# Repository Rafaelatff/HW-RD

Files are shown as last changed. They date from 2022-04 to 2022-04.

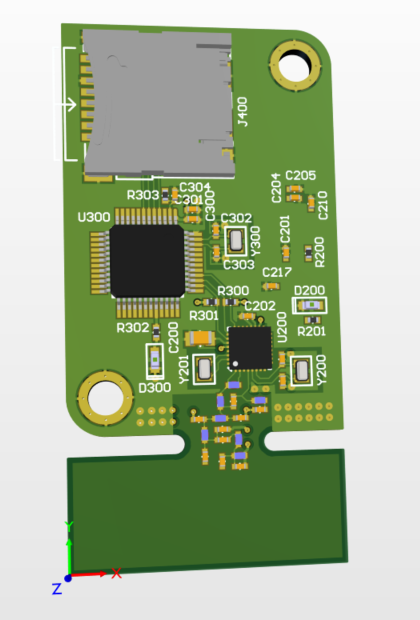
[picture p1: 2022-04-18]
3D files/Challenge-NOT-FINISHED.png

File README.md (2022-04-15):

# HW-RD
TRACTIAN challenge - Hardware R&amp;D

*Goal: Develop a full wireless communication system. It needs to send a 500 kB file from a 100 m open-air gap, using at least one battery powered device.*

## Step 1: Scketch it up! 

**1.1 - Let's find the main wireless component**

The preference for manufacturer goes to Texas Instruments due its good variety of components, good documentation, tools for simulation and development. 

According to: https://training.ti.com/range-test-cc1120-sub-1-ghz-performance-line, 100 m air-gap is reachable with a Sub-1GHz system.

Texas instruments shows 36 parts classified as Sub-1GHz products. All 36 were checked, but only active part numbers and with at least one place with available stock entered the comparing table below. Preference for available SPI to add external memory. There were no operating temperature requirements for the wireless communication system, nor minimum of peripheral required.  So none of those were considered componente elimination factors. It is a battery powered device, so, it must be low power.
The table below compares TI inventory and also Mouser and Digikey (two biggest global electronic components purveyor).

| Part Number | TI Inventory | Price | Mouser | Price | Digikey | Price |
|---|---|---|---|---|---|---|
| CC1311P3 | 2418 | $3.125 | Non-Stocked | $4.8 (x2500) | 0 | $8.92 |
| CC1312R7 | 2200 | $3.795 | Non-Stocked | $5.83 (x2500) | - | - |
| CC1352P | 0 | $3.917 | CC1352P1F3RGZT -107 CC1352P1F3RGZR – 5061 (On order) | $11.86 $9.89 | 0 | $9.4 |
| CC1312R | 0 | $3.341 | CC1312R1F3RGZR (7806 Expected 10/3/2022) | $8.43 | 0 | $8.02 |
| CC430F5143 | 376 | $2.34 | Non-Stocked | $5.05 (x250) | CC430F5143IRGZT - 250 | $6.74 |
| **CC1350** | **5167** | **$3.446** | **CC1350F128RSMR – 5148 CC1350F128RSMT - 257** | **$8.96 $10.7** | **CC1350F128RSMR – 841 CC1350F128RHBR - 644** | **$9.37 $8.27** |
| **CC1310** | **19084** | **$2.052** | **CC1310F32RSMR – 11472 CC1310F32RGZR - 1318** | **$5.76 $6.05** | **CC1310F128RGZR – 2212 CC1310F32RGZT - 214** | **$6.89 $6.15** |
| CC1200 | 7990 | $1.928 | 0 | $5.42 | 0 | $6.48 |
| CC1100E | 0 | $1.139 | CC1100ERGPT - 57 | $3.84 | CC1100ERGPT - 149 | $3.83 |

Note : research done in April, 11th. 
https://www.ti.com/wireless-connectivity/products.html 
https://br.mouser.com/
https://www.digikey.com

Now, let's compare Technologies. Note: values from TI site - production details (datasheet may show accurate data and were not considered, since it consumes a lot of time).

| Part Number | Available devkit? | Microcontroller | Peripherals | Memory | Power (active mode/standby mode/transmission mode*) |
|---|---|---|---|---|---|
| CC1311P3 | Not found | 48-MHz Arm Cortex-M4 processor | 1 SPI, 1 UART, 12-bit ADC 8-channel, 2 comparators, 4 timers, I2C, I2S, 26 GPIO | 32 KB RAM + 352 KB flash | 2.63 mA/ 0.7 uA / 65 mA |
| CC1312R7 | LP-CC1312R7 (10 - $69.94) | 48-MHz Arm® Cortex®-M4F processor | 12-bit ADC 8-channel, 2 SPI, 2 UART, 2 comparators, 4 timers, 8-bit DAC, I2C, I2S, Sensor controller, 30 GPIO | 256 KB ROM+ 704 KB flash | 2.63 mA/ 0.8 uA / 24.9 mA |
| CC1352P | LAUNCHXL-CC1352P1 (183 - $66.49)  | 48-MHz Arm Cortex-M4F processor | 2 SPI, 2 UART, 2 comparators, 4 timers, 8-bit DAC, I2S, Sensor controller, 26 GPIO | 256 KB ROM + 352 KB flash | 5.8 mA/ 0.85 uA / 24.9 mA |
| CC1312R | LAUNCHXL-CC1312R1 (85 - $53.19) | 48-MHz Arm Cortex-M4F processor | 2 SPI, 2 UART, 2 comparators, 4 timers, 12-bit ADC, I2S, Sensor controller, 30 GPIO | 80KB SRAM + 256 KB ROM + 352 KB flash | 5.8 mA/ 0.85 uA / 24.9 mA |
| CC430F5143 | Not found | True System-on-Chip (SoC) for Low-Power Wireless Communication Applications / 16-Bit RISC Architecture | I2C, UART,  2x SPI, 2 timers, 10-bit ADC | 4 KB RAM +  32 KB flash | 160 uA / 2 uA/ 15 mA |
| CC1350 | CC1350STKUS (82 - $78.47) LAUNCHXL-CC1350US (22 - $38.57) | 48-MHz Arm® Cortex®-M3 Processor | 1 UART, 12-bit ADC 8-channel, 2 SPI, 2 comparators, 4 timers, I2C, I2S, Sensor controller, GPIO according to package (10, 15 or 30) | 28KB SRAM + 128 KB flash | 5.4 mA/ 0.7 uA/ 13.4 mA |
| CC1310 | LAUNCHXL-CC1310 (122 - $38.57) | 48-MHz Arm® Cortex®-M3 | 1 UART, 12-bit ADC 8-channel, 2 SPI, 2 comparators, 4 timers, I2C, I2S, Sensor controller, GPIO according to package (10, 15 or 30) | 28 KB SRAM + 128 KB flash | 5.4 mA/ 0.7 uA/ 13.4 mA |

Note : To have an available devkit helps development tasks (once production firmware may start together with hardware development and even help to find issues).  Let's not forget of the  time to market..

Links: 
https://training.ti.com/ti-simplelink-sub-1-ghz-wireless-solutions-iot-technical-introduction-level-1

https://www.ti.com/design-resources/embedded-development/wireless-connectivity.html

https://www.ti.com/lit/sg/swat016b/swat016b.pdf

CC1310 User guide: https://www.ti.com/lit/ug/swcu117i/swcu117i.pdf

CC1310 Datasheet: https://www.ti.com/lit/ds/symlink/cc1310.pdf

Xtal selection guideline: https://www.ti.com/lit/an/swra495i/swra495i.pdf (not really followed due to small amount of time available to the challenge)

**Pin mapping - RSM Package (VQFN-32)**

| Pin name | Pin number | Type | Description | 
|---|---|---|---|
| DCDC_SW | 18 | Power | Output from internal DC/DC |
| DCOUPL | 12 | Power | 1.27-V regulated digital-supply decoupling capacitor |
| DIO_0 | 8 | Digital I/O | GPIO, Sensor Controller, high-drive capability |
| DIO_1 | 9 | Digital I/O | GPIO, Sensor Controller, high-drive capability |
| DIO_2 | 10 | Digital I/O | GPIO, Sensor Controller, high-drive capability |
| DIO_3 | 15 | Digital I/O | GPIO, high-drive capability, JTAG_TDO |
| DIO_4 | 16 | Digital I/O | GPIO, high-drive capability, JTAG_TDI |
| DIO_5 | 22 | Digital or analog I/O | GPIO, Sensor Controller, analog |
| DIO_6 | 23 | Digital or analog I/O | GPIO, Sensor Controller, analog |
| DIO_7 | 24 | Digital or analog I/O | GPIO, Sensor Controller, analog |
| DIO_8 | 25 | Digital or analog I/O | GPIO, Sensor Controller, analog |
| DIO_9 | 26 | Digital or analog I/O | GPIO, Sensor Controller, analog |
| EGP | - | Power | Ground; exposed ground pad |
| JTAG_TMSC | 13 | Digital I/O | JTAG_TMSC |
| JTAG_TCKC | 14 | Digital I/O | JTAG_TCKC |
| RESET_N  | 21 | Digital input | Reset, active low. No internal pullup |
| RF_N | 2 | RF I/O  | Negative RF input signal to LNA during RX Negative RF output signal from PA during TX |
| RF_P | 1 | RF I/O | Positive RF input signal to LNA during RX Positive RF output signal from PA during TX |
| RX_TX | 4 | RF I/O  | Optional bias pin for the RF LNA |
| VDDS | 27 | Power | 1.8-V to 3.8-V main chip supply |
| VDDS2 | 11 | Power | 1.8-V to 3.8-V GPIO supply |
| VDDS_DCDC | 19 | Power | 1.8-V to 3.8-V DC/DC supply |
| VDDR | 28 | Power | 1.7-V to 1.95-V supply, connect to output of internal DC/DC |
| VDDR_RF | 31 | Power | 1.7-V to 1.95-V supply, connect to output of internal DC/DC |
| VSS | 3, 7, 17, 20, 29  | Power | Ground |
| X32K_Q1 | 5 | Analog I/O | 32-kHz crystal oscillator pin 1 |
| X32K_Q2 | 6 | Analog I/O | 32-kHz crystal oscillator pin 2 |
| X24M_N | 30 | Analog I/O | 24-MHz crystal oscillator pin 1 |
| X24M_P | 31 | Analog I/O | 24-MHz crystal oscillator pin 2 |

**1.2 - Let's find the hw peripherals**

**1.2.1 - Power supply**

Function and characteristics: filter and regulate battery voltage; low LDO; low quiescent current; 

**1.2.2 - Secondary low power microcontroller**

Function and characteristics: control and manage secondary tasks; comunicate with wireless microcontroller; low power;

PN: MSP430FR2476 Mnf: Texas Instruments Datasheet: www.ti.com/lit/ds/symlink/msp430fr2476.pdf

Used pins:
| Pin number | Port.Pin | Type/Peripheral | Description | 
|---|---|---|---|
| 1 | DVCC | Power | VDD |
| 2 | SBW | JTAG/SBW | JTAG/SBW |
| 3 | SBW | JTAG/SBW | JTAG/SBW |
| 4 | P1.4 | UCA0SIMO | eUSCI_A0 SPI slave in/master out |
| 5 | P1.5 | UCA0SOMI | eUSCI_A0 SPI slave out/master in |
| 6 | P1.6 | UCA0CLK | eUSCI_A0 SPI clock input/output |
| 7 | P1.7 | UCA0STE |  eUSCI_A0 SPI slave transmit enable |
| 8 | P4.3 | GPIO | SPI_INT |
| 37 | P3.5 | GPIO | I2C_INT |
| 38 | P3.2 | UCB1SDA | eUSCI_B1 I2C data |
| 39 | P3.6 | UCB1SCL | eUSCI_B1 I2C clock |
| 46 | XOUT | Xtal | Crystal out |
| 47 | XIN | Xtal | Crystal in |
| 48 | DVSS | Power | GND |

**1.2.3 - External memory or microSD card**

Function and characteristics: accomodate data; save logs; SPI communication;

Guidelines: 
https://www.kingston.com/datasheets/SDCIT-specsheet-64gb_en.pdf
https://www.st.com/resource/en/application_note/an5595-spc58xexspc58xgx-multimedia-card-via-spi-interface-stmicroelectronics.pdf

microSD card connector PN: DM3C-SF / Manufacturer: Hirose Electric Co Ltd 

**1.2.4 - Accelerometer**

Function and characteristics: main parameter to be monitored;

**1.2.5 - Battery**

Function and characteristics: 3.6 V; Lithium batteries (ultra-low power);

## Step 2: It’s layout time

For Altium project -> HW-RD/tree/main/Altium%20Project

For 3D project -> HW-RD/tree/main/3D%20files

Antenna guidelines: https://www.ti.com/lit/an/swra726/swra726.pdf

Layout must have the rules according to the capability of the third party company that will manufacturer the PCB (example: https://www.griffuspcb.com.br/files/anexo1-34-parametros-de-processo-e-produto-rev-05.pdf). Impedance values for PCB tracks must follow recommendation of third party company that will manufacturer the PCB together with Saturn PCB toolkit. Since time is short, just Saturn PCB toolkit will be used.

## Step 3: Write some code!

For CC1310 code -> HW-RD/tree/main/CC1310

For MSP430 code -> HW-RD/tree/main/MSP430

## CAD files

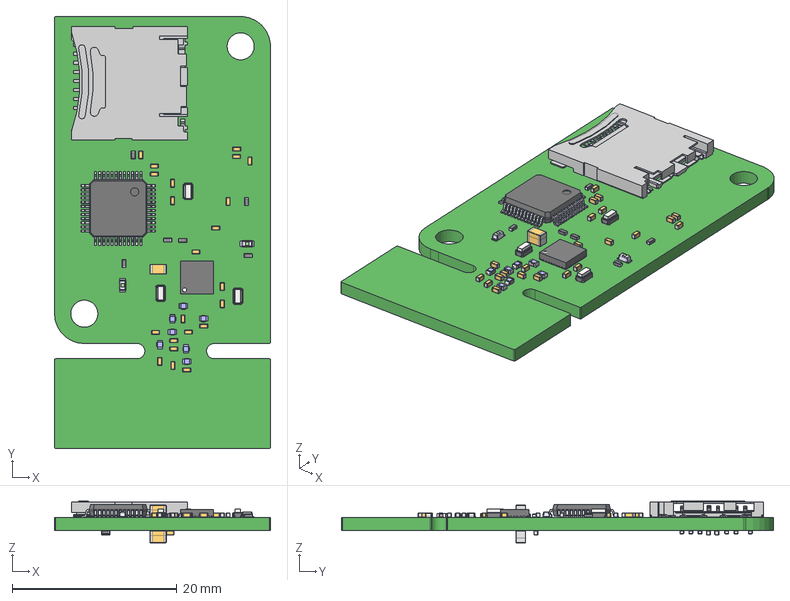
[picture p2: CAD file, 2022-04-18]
3D files/TRACTIAN-HW-Challenge.step
26.3 x 52.5 x 5.06 mm
Board
R0402 x 12
LED_SMD_0603 x 2
Extruded x 5
CAPC1005X56N_EIA_0402 x 25
Coilcraft-0402ME x 7
User_Library-ABS06_ABS06_Body_2 x 3
User_Library-ABS06_ABS06_Body2_2 x 3
User_Library-ABS06_ABS06_Beschriftung_2 x 3
User_Library-ABS06_ABS06_Pads_2 x 3
CAPC2012X95N_EIA_0805 x 4
DM3CS-SF
LQFP48_Koerper_2
LQFP_PIN_2 x 48
pins
pins_small x 32
pin_label x 8

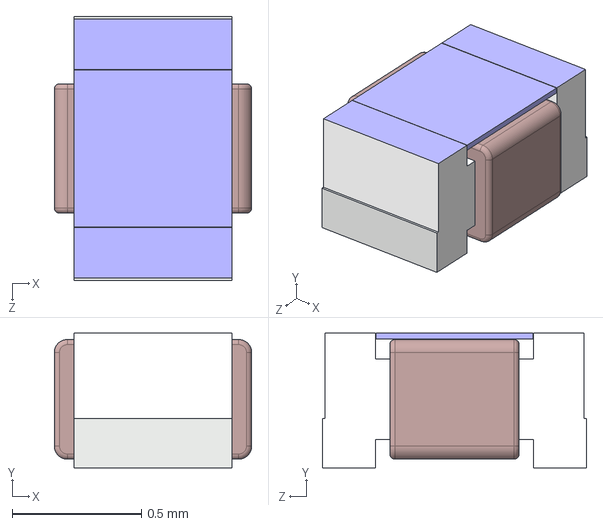
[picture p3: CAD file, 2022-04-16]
Altium Project/3D parts/Coilcraft-0402ME.STEP
0.762 x 0.521 x 1.02 mm

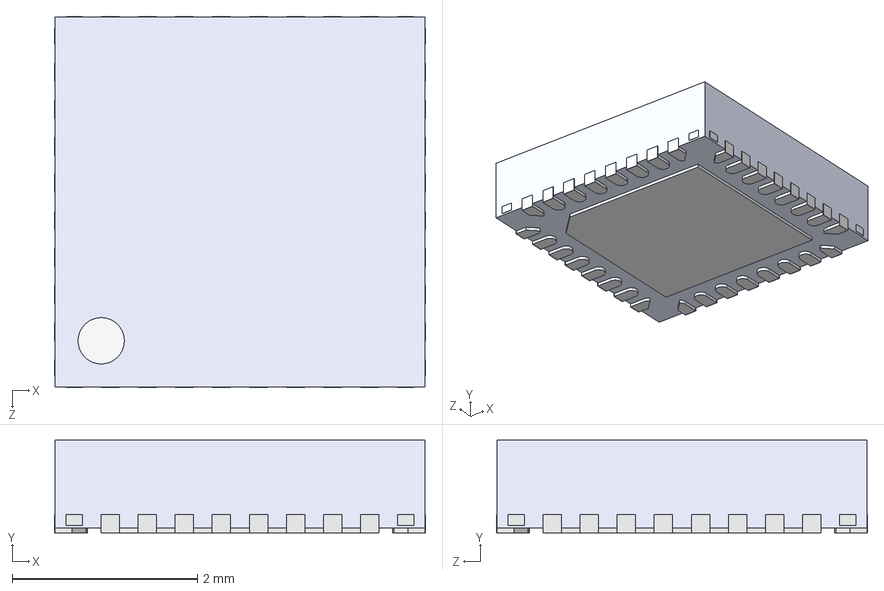
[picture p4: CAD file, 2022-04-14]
Altium Project/3D parts/User Library-QFN32-0_4.STEP
4.01 x 1.00 x 4.01 mm
pins
pins_small x 32
pin_label x 8

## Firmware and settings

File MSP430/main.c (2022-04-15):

//CCS version 10.2.0.00009
#include <msp430.h>
#include <string.h> //to use strlen() function
#include <assert.h> // to use asset function
#include <stdio.h>

char message = 0;
char Data_In = 0;


int x = 19;
int y=0;
//size 20, goes from Data_In_Array[0] until Data_In_Array[19], being [0] reg addred + [0x00 to 0x12] data
char Data_In_Array[20];

int ACLK_clock;

void I2C_B1_slave_config(void);
void SPI_A0_config(void);
int BCDtoDecimal(int data);
int DecimalToBCD(int data); //not needed!
void delay_ms(int time);
void start_clock_sys(void);

int main(void)
{
     WDTCTL = WDTPW | WDTHOLD;   // stop watchdog timer

    // Set LED1 for test routines
    // Set P1.0 as output direction [J7 needs to be connected]
    // LED White: Port P1 / Pin 0
    P1SEL0 &= ~BIT0;
    P1SEL1 &= ~BIT0;
    P1DIR |= BIT0; // Set LED1 as Output
    P1OUT &= ~BIT0; // turn off LED1

    PM5CTL0 &= ~LOCKLPM5;       //to apply the GPIO configurations disable the LOCKLPM5 bit in PM5CTL0
    //unlock the GPIO high-impedance mode by resetting the LOCKLPM5 bit

    I2C_B1_slave_config(); // Config MSP as slave

    P1OUT |= BIT0; // LED1

    while (1){

        __delay_cycles(78000);
        P1OUT ^= BIT0; // LED0
    }
}
//-------------ISR-----------------
#pragma vector = EUSCI_B1_VECTOR
__interrupt void EUSCI_B1_I2C_ISR(void){
    switch(UCB1IV){
    case 0x16:  // ID 16: RXIFG0 according to MSP430FR4xx and MSP430FR2xx family user's guide
            //while (!(UCB1IFG & UCRXIFG0));
            Data_In = UCB1RXBUF; // Read data from RX buffer
        break;
    case 0x18:  // ID 18: TXIFG0 according to MSP430FR4xx and MSP430FR2xx family user's guide
            UCB1TXBUF = message; // Send data from TX buffer
        break;
    default:
        break;
    }
}

// Timer A0 interrupt service routine
#if defined(__TI_COMPILER_VERSION__) || defined(__IAR_SYSTEMS_ICC__)
#pragma vector = TIMER0_A0_VECTOR
__interrupt void Timer_A (void)
#elif defined(__GNUC__)
void __attribute__ ((interrupt(TIMER0_A0_VECTOR))) Timer_A (void)
#else
#error Compiler not supported!
#endif
{
    ACLK_clock++;

    //P1OUT ^= BIT0;
    TA0CCR0 +=1; // Add Offset to TACCR0
}



int BCDtoDecimal (int data){
 // Convert from BCD to Decimal
 // Step 1: Break the BCD into nibbles: 1001 0001 0001 · Step 2: Convert each nibble into decimal digits.
    assert(((data & 0xF0) >> 4) < 10);  // Test if more significant nybble is valid
    assert((data & 0x0F) < 10);         // Test if less significant nybble is valid
    //not expected to receive hexadecimals greater than 9
    int dec = ((data & 0xF0) >> 4) * 10 + (data & 0x0F);
    return dec;
 // x % y   module operator: x mod y: produces the remainder when x is divided by y.
 // 59 mod 16 = 11 -> 59 = (16×3) + 11
    //mod garantes  that value wont be bigger
    // (((data/1000)<<8) | ((data/10)<<4) | (Decimal % 10));
}

void I2C_B1_slave_config(void){

    /*   eUSCI_B Registers
     *      UCBxCTLW0 (eUSCI_Bx Control Register 0)
     *      UCBxBRW R (eUSCI_Bx Bit Rate Control Register 1)
     *      UCBxSTATW (eUSCI_Bx Status Register)
     *      UCBxRXBUF (eUSCI_Bx Receive Buffer Register)
     *      UCBxTXBUF (eUSCI_Bx Transmit Buffer Register)
     *      UCBxIE    (eUSCI_Bx Interrupt Enable Register)
     *      UCBxIFG   (eUSCI_Bx Interrupt Flag Register) --> (0 = No interrupt pending / 1 = Interrupt pending)
     *          UCRXIFG0  0x01   - eUSCI_B receive interrupt flag 0 - is set when UCBxRXBUF has received a complete character (M/S mode)
     *          UCTXIFG0  0x02   - eUSCI_B transmit interrupt flag 0  - UCTXIFG0 is set when UCBxTXBUF is empty (M/S mode)
     *          UCSTTIFG  0x04   - START condition interrupt flag
     *          UCSTPIFG  0x08   - STOP condition interrupt flag
     *          UCALIFG   0x10   - Arbitration lost interrupt flag
     *          UCNACKIFG 0x20   - Not-acknowledge received interrupt flag
     *          UCBCNTIFG 0x40   - Byte counter interrupt flag - Is set when byte counter threshold value UCBxTBCNT is reached (M/S mode)
     *          UCCLTOIFG 0x80   - Clock low time-out interrupt flag
     *          UCRXIFG1  0x100  - Receive interrupt flag 1
     *          UCTXIFG1  0x200  - eUSCI_B transmit interrupt flag 1
     *          UCRXIFG2  0x400  - Receive interrupt flag 2
     *          UCTXIFG2  0x800  - eUSCI_B transmit interrupt flag 2
     *          UCRXIFG3  0x1000 - Receive interrupt flag 3
     *          UCTXIFG3  0x2000 - eUSCI_B transmit interrupt flag 3
     *          UCBIT9IFG 0x4000 - Bit position 9 interrupt flag
     */

    // always put the eUSCI module into its reset state
    UCB1CTLW0 = UCSWRST;                      //Put B1 in SW reset

    // slave config
    UCB1CTLW0 |= UCMODE_3; //put into I2C mode (others options configure the eUSCI as SPI communication)
    UCB1CTLW0 |= UCSYNC; // Synchronous mode
    UCB1CTLW0 &= ~UCMST; // set as slave

    UCB1I2COA0 = 0x66; // Set slave address
    UCB1I2COA0 |=UCGCEN; //The slave address defined in I2COA0 is enabled

    UCB1CTLW1 |= UCASTP_2; //Auto STOP mode -> UCASTP_2 = 0x8 = 0b1000 = 10 (bits 2 and 3 of UCBxCTLW1 register [0to15])
    UCB1TBCNT = 1; // transfer buffer count = size of Packet array

    //Config PIN SEL  - for UCB0SDA e UCB0SCL PxSELx = 01
    //SDA pin 14 (P1.2) - UCB0SDA
    //SCL pin 15 (P1.3) - UCB0SCL
    //P1SEL0 |= BIT2 | BIT3;
    //P1SEL1 &= ~(BIT2 | BIT3);

    //To use UCB1SDA e UCB1SCL
    //SDA pin 38 (P3.2) - UCB1SDA
    //SCL pin 39 (P3.6) - UCB1SCL
    P3SEL0 |= BIT2 | BIT6;
    P3SEL1 &= ~(BIT2 | BIT6);

    //Obs.: To set an interrupt for I2C (in case MSP is slave), set an ordinary GPIO (P3.5);
    P3SEL0 &= ~BIT5;
    P3SEL1 &= ~BIT5;
    P3DIR |= BIT5; // Set as Output
    P3OUT &= ~BIT5; // Stay low

    PM5CTL0 &= ~LOCKLPM5;  // to apply the GPIO configurations disable the LOCKLPM5 bit in PM5CTL0
    UCB1CTLW0 &= ~UCSWRST;  //Take B1 out of SW RST

    //Enable B1 TX0 and RX0 IRQ
    UCB1IE |= UCTXIE0;  // local enable for TX0
    UCB1IE |= UCRXIE0;  // local enable for RX0
    __enable_interrupt(); // enable maskables
}


void SPI_A0_config(void){
    //To be continued;
}

void start_clock_sys(void){
    //Clock configured as counter mode
    //Timer configuration: 16 bits = 65.536 - 1 (0 até 65535/ 0x0 até 0xFFFF)
    //Timer A Instance 0 (TA0) -> Compare/Capture Register 0 (CCR0)
    //1 - To set Enable bit:
       TA0CCTL0 |= CCIE;
    //Now the MSP430 will interrupt once the timer reaches TA0CCR0.
    //2 - Choose value for TA0CCR0:
       TA0CCR0 = 1;
    //3 - Choose clock source for Timer_A0 and also choose Continuous Mode:
    //ACLK = 32678 Hz
       TA0CTL |= TASSEL__ACLK | MC__CONTINUOUS;
    //It will enter ISR of timer A each 1/32678 seconds -> 30.6 us
    //1ms = 32678 clocks
    //4 - Enable global interrupts in the MSP430 so that we can perform an action once TA0R = TA0CCR0.
       __bis_SR_register(GIE);
}

void delay_ms(int time){
    //Time isn't very accurate, but enought for applications
    int count;
    for (count=0;count<=time;count++){
        ACLK_clock=0;
        while(ACLK_clock<=30);
    }
    //place following lines in main to test
    /* while(1){
        P5OUT ^= BIT3; // LED0
        delay_ms(10);
    }*/
}

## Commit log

2022-04-14 adding altium files; created main wireless component
    [Blocks.SchDoc, TRACTIAN-HW-Challenge.PcbDoc, TRACTIAN-HW-Challenge.PcbLib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]
2022-04-15 added sysconfig file; added low mcu to project;
    [Blocks.SchDoc, TRACTIAN-HW-Challenge.PcbLib, TRACTIAN-HW-Challenge.PrjPCB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]
2022-04-16 added most of the sch components; added footprints
    [Blocks.SchDoc, Coilcraft-0402ME.STEP, TRACTIAN-HW-Challenge.PcbDoc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]
2022-04-18 Created PCB, add existing components and route part of the project -NOT FINISHED
    [TRACTIAN-HW-Challenge.PcbDoc, TRACTIAN-HW-Challenge.PcbLib, TRACTIAN-HW-Challenge.PrjPCB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]
